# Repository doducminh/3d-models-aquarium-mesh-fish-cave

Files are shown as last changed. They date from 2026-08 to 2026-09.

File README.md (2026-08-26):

# Bông sen nổi — hang trú ẩn cho cá betta

Một bông sen đang nở, cánh xoè ngay trên mặt nước. Bên dưới mặt nước là **bầu lưới
làm hang cho cá**. Nhuỵ ở giữa là lưới lỗ để nhìn xuyên xuống hang.

Cửa hang **tháo lắp được ngay trong nước bằng một tay** — gắn vào thì cả vật thành
lồng cách ly betta tạm thời.

**[Xem mô hình 3D →](viewer/index.html)**

---

## Hợp với hồ nào

Betta (dài ~10 cm) và đàn nhỏ — guppy, neon, cá chuột. Dựng cho hồ 45 × 30 cm.

Lá sen Ø140 · bông Ø99 cao 42 · cổ Ø44 · 28 cánh. **Dự trữ nổi 1,86×** — nó nổi
nhờ hình dạng, không cần phao, không cần dằn.

---

## Chi tiết — bốn mảnh, 173 g, 24h32

| File | Là cái gì | Nhựa | Thời gian | Số bản |
|---|---|---|---|---|
| `stl/v9/lotus-body.stl` | Thân + lá sen. Bầu lưới làm hang nằm dưới mặt nước | 96,1 g | 13h46 | 1 |
| `stl/v9/lotus-petals.stl` | Bông sen — các hàng cánh xoè trên mặt nước | 63,2 g | 8h44 | 1 |
| `stl/v9/lotus-door.stl` | **Cửa hang tháo lắp được trong nước** | 5,7 g | 1h13 | 1 |
| `stl/v9/lotus-cover.stl` | Nắp che sáng đậy nhuỵ | 7,8 g | 0h51 | 1 |
| `stl/v9/water-level.stl` | Đĩa đánh dấu mực nước cho viewer — **không bao giờ in** | — | — | 0 |

`lotus-body` mất gần 14 tiếng một mẻ — cân nhắc lịch máy trước khi bắt đầu.

### Cửa mở bằng cách BÓP, không phải kéo

Vật này **đang nổi**. Kéo, đẩy hay bẩy đều là lực có tổng khác không nên cả bông
sen đi theo tay chứ không chịu mở — và dự trữ nổi chỉ mua được khoảng **145 gf**
trước khi cả vật bị nhấc lên hoặc nhấn chìm, mà cái chốt đủ chặt để cá không đẩy ra
cũng cỡ đó.

Bóp hai nút cho chúng lại gần nhau thì **tổng lực bằng 0**, và động tác bóp đồng
thời kẹp lấy chi tiết nên nhả xong rút ra được luôn. Một tay, trong nước, không
phải thò cả cánh tay xuống hồ.

---

## Vật liệu — PETG, không có ngoại lệ

Ngâm nước **vĩnh viễn**. PLA thuỷ phân trong vài tháng, giòn ra rồi vỡ thành **mảnh
sắc ngay trong hồ có cá đang sống**.

Dùng PETG **trong hoặc trắng nguyên sinh**. Không dùng nhựa tái chế hoặc nhựa có
phụ gia màu lạ.

---

## Cài đặt in

Vòi 0,4 · lớp 0,2 · **không support** (đo được 0% trong cả bốn file gcode) · đã ở
đúng tư thế in trong file.

Vòm lưới in được không support là **kết quả của biên dạng**, không phải nhờ khoét
lỗ. Khoét lỗ chỉ bớt *diện tích* mặt dốc chứ không chia *mảng* — mặt trong vỏ vẫn
liên thông qua chính mạng gân. Bản dùng vòm ellipse đo ra **một mảng dốc liền
1337 mm²**, gấp 6,7 lần ngưỡng an toàn; phải đổi sang cung vai cộng côn 43° thì
mảng lớn nhất mới xuống dưới 200 mm².

Nửa cầu và ellipse thì **vô phương**: tiếp tuyến ở đỉnh nằm ngang nên độ dốc luôn
tiến tới 90°.

---

## Nguồn gốc

Ý tưởng ban đầu từ một sản phẩm bán sẵn (vòm lưới Ø70 × cao 40, vành loe ở đáy, một
cửa vào lớn). Bản này **không sao chép hình dạng đó** — từ phiên bản thứ hai trở đi
nó đã thành một vật khác hẳn: nổi thay vì chìm, hình bông sen thay vì vòm trơn.

Bản chìm đặt đáy hồ (`mesh-cave.stl`) còn trong lịch sử repo nếu bạn nuôi cá chuột
— loài không bao giờ dùng đồ nổi.

---

## Trạng thái

⚠️ **Chưa in lần nào, và chưa khắc dấu bản quyền.** CAD, STL, viewer và gcode đủ
bốn mảnh với 0% support — nhưng đó là số đo trên mô hình.

---

## Giấy phép

[CC BY-NC-SA 4.0](LICENSE) — dùng tự do phi thương mại, ghi nguồn
`github.com/doducminh`, bản sửa phát hành cùng giấy phép.

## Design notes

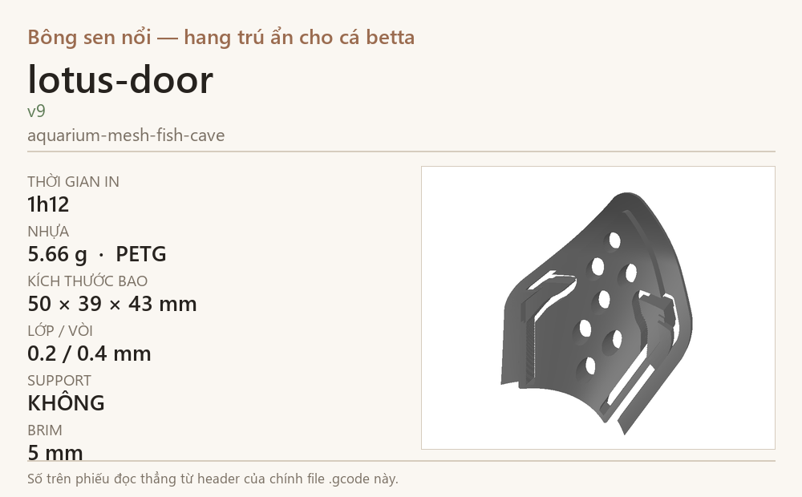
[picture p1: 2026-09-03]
gcode/v9/lotus-door.png

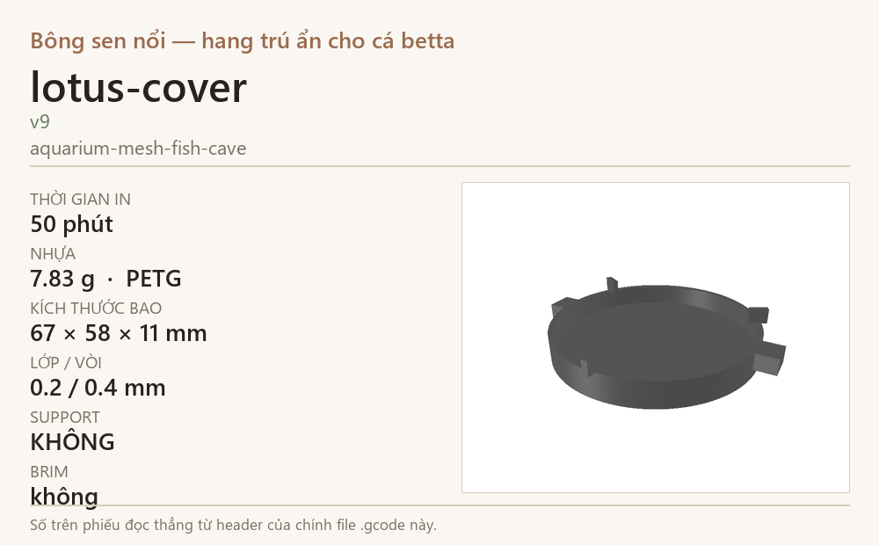
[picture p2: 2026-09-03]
gcode/v9/lotus-cover.png

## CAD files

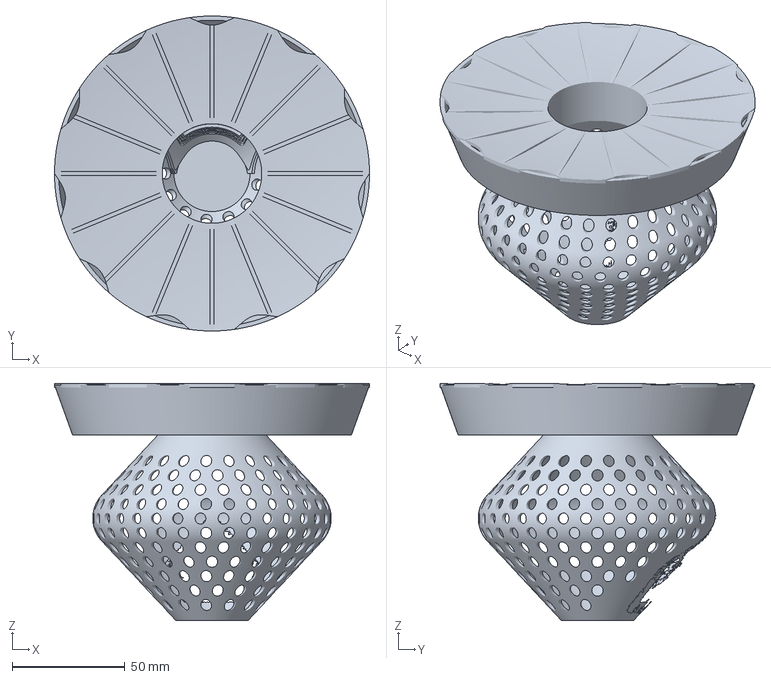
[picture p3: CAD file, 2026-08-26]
gcode/v9/lotus-body.3mf
140.0 x 140.0 x 105.5 mm

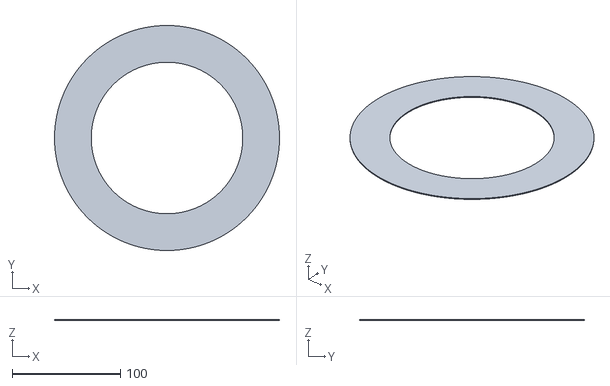
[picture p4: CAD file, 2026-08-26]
stl/v9/water-level.stl
208.0 x 208.0 x 0.8

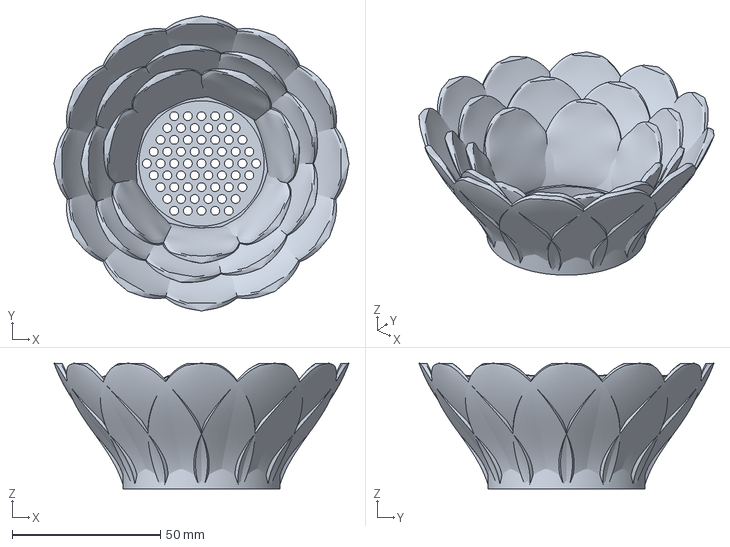
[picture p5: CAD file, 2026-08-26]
gcode/v9/lotus-petals.3mf
99.4 x 99.4 x 42.3 mm

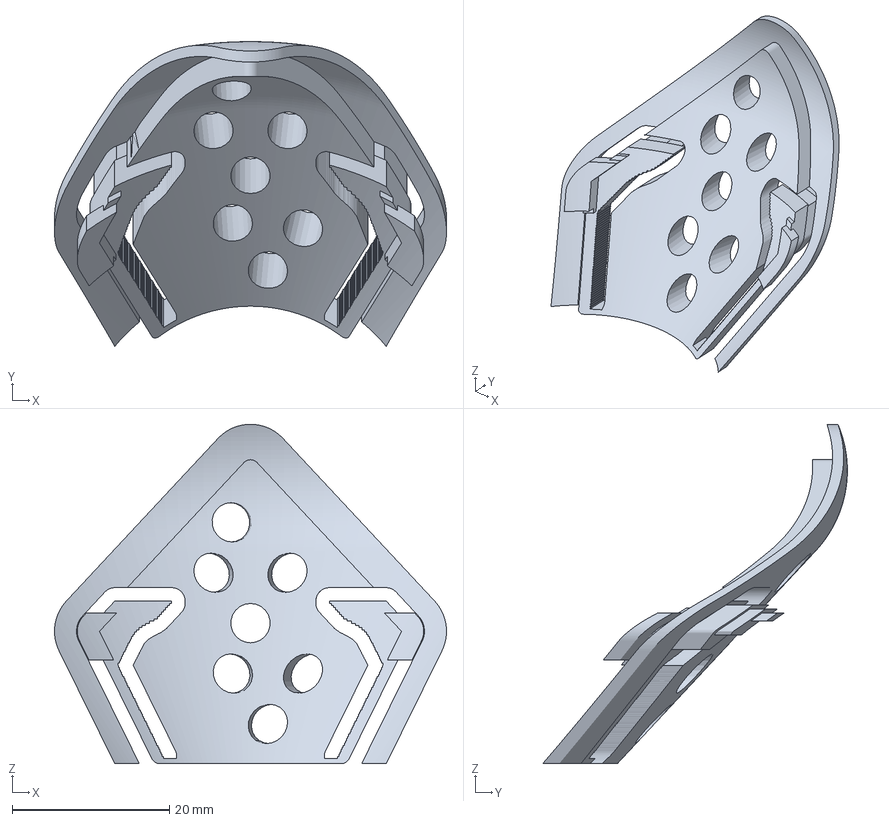
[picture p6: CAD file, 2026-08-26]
gcode/v9/lotus-door.3mf
49.8 x 38.7 x 43.1 mm

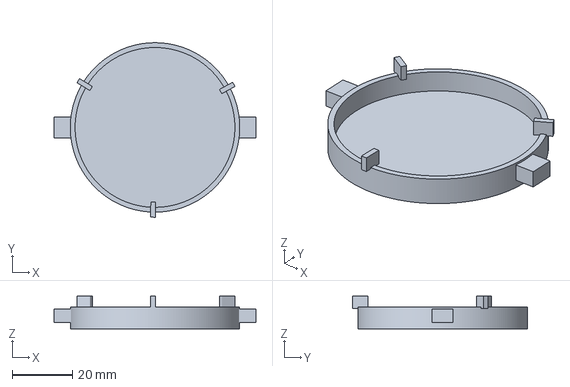
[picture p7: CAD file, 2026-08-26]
gcode/v9/lotus-cover.3mf
67.0 x 57.9 x 10.8 mm

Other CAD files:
stl/v9/lotus-petals.stl
stl/v9/lotus-body.stl
stl/v9/lotus-door.stl
stl/v9/lotus-cover.stl

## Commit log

2026-08-26 File thanh pham ban dau: STL, gcode, viewer
    [lotus-body.3mf, lotus-body.stl, lotus-cover.3mf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]
2026-08-26 README + LICENSE + viewer cho repo cong khai
    Bổ sung ba thứ checklist mục 10 đòi trước khi push công khai: README
    (ảnh/chi tiết/vật liệu/cài đặt in/cách lắp), LICENSE CC BY-NC-SA 4.0,
    và viewer 3D mở được bằng trình duyệt.
2026-09-03 Phieu anh cho moi file .gcode
    Nhung thumbnail vao chinh gcode (khoi `;gimage:`/`;simage:` cho man hinh Elegoo
    Neptune, va khoi `; thumbnail` chuan PrusaSlicer/Klipper), va them mot file .png
    cung ten nam canh de xem tren may tinh.
    Tren USB thi moi thu chi con la mot cai ten khong dau — phieu nay tra loi "day la
    cai gi": ten chi tiet, ten du an, thoi gian in, so gam, vat lieu, be day lop,
    support, brim, va hop bao THAT cua chi tiet.
    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
